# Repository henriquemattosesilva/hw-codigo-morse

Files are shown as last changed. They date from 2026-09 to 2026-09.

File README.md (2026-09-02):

# Telégrafo sem fio em código morse

Um manipulador de morse com um botão no Arduino Nano transmite por rádio
433 MHz para um receptor, que mostra a mensagem decodificada num LCD 16x2.
São **dois receptores possíveis**: um Arduino Uno, mais simples, e um ESP8266,
que além do LCD publica a mensagem na internet.

O botão é uma chave telegráfica de verdade: toque curto vira ponto, toque longo
vira traço, e as pausas separam as letras e as palavras. Você escreve qualquer
coisa, não uma mensagem programada de antemão.

```
   botão                                            LCD 16x2
     │                                                 ▲
     ▼                                                 │
   NANO  ──►  433 MHz  ))))))))))))))))))))  ──►  UNO ─┘
     │                                             │
  3 LEDs + buzzer                            LED + botão limpar
```

## Arquivos

**A página do projeto reúne tudo — componentes, montagem com diagramas, código das
duas placas e melhorias — numa tela só, boa de consultar no celular durante a montagem:**

### 👉 https://henriquemattosesilva.github.io/hw-codigo-morse/

Ela também traz um manipulador de morse que funciona no navegador, com os mesmos LEDs
e o mesmo display do projeto real. Dá para treinar antes de montar qualquer coisa.

| Arquivo | O que é |
|---|---|
| [index.html](index.html) | a página do projeto, publicada no GitHub Pages |
| [MONTAGEM.md](MONTAGEM.md) | esquema de ligação, ordem de teste e o que fazer quando não funciona |
| [transmissor-nano/](transmissor-nano/) | sketch do Nano (manipulador) |
| [receptor-uno/](receptor-uno/) | sketch do Uno (display) |
| [receptor-esp8266/](receptor-esp8266/) | sketch do ESP8266 (display + internet) |
| [MONTAGEM-ESP8266.md](MONTAGEM-ESP8266.md) | montagem do receptor com ESP8266 |
| [ao-vivo/](ao-vivo/) | a página que mostra a mensagem ao vivo |
| [ferramentas/](ferramentas/) | scripts que geram os diagramas e a página |
| [docs/superpowers/specs/](docs/superpowers/specs/) | o projeto escrito, com as decisões e os porquês |

O `index.html` é **gerado**, não editado à mão. Depois de mexer num sketch ou nos
diagramas, rode:

```
python ferramentas/gerar-diagramas.py   # só se mudou a fiação
python ferramentas/gerar-pagina.py      # sempre
```

## Os dois receptores

| | Arduino Uno | ESP8266 |
|---|---|---|
| Lógica | 5 V, liga o rádio direto | 3,3 V, **exige divisor** no DATA do rádio |
| Pinos | qualquer um serve | três são lidos no boot e mudam quem vai onde |
| Rádio | sozinho no processador | disputando com a pilha de WiFi |
| Mensagem | 15 letras no LCD | 160 guardadas, 15 no LCD, e **na internet** |

**Comece pelo Uno.** Ele prova que o rádio funciona sem trazer junto WiFi, tensão de
3,3 V e divisor resistivo. Trocar a placa da ponta depois é rápido.

Com o telégrafo com ESP8266 ligado, a mensagem aparece ao vivo em
**https://henriquemattosesilva.github.io/hw-codigo-morse/ao-vivo/** — a montagem está
no [MONTAGEM-ESP8266.md](MONTAGEM-ESP8266.md).

> A saída de dados do módulo de rádio entrega 5 V, e os pinos do ESP8266 não toleram
> isso. O divisor de 10 kΩ + 20 kΩ não é opcional.

**Comece pelo [MONTAGEM.md](MONTAGEM.md).** A única biblioteca a instalar é a
**RadioHead**, pelo Gerenciador de Bibliotecas da IDE.

## Os LEDs do transmissor

O difícil no morse é que os tempos são invisíveis: você não sabe se o aperto já
virou traço até a letra sair errada. Os três LEDs mostram exatamente os limiares,
e acendem **antes** de você soltar o botão.

| O que você vê | O que significa |
|---|---|
| um verde aceso | o toque em curso ainda vale um **ponto** |
| os **dois** verdes acesos | o toque passou de 2 unidades, virou **traço** |
| azul aceso | o silêncio passou de 3 unidades: a **letra fechou e foi enviada** |
| azul piscando duas vezes | o silêncio passou de 7 unidades: **espaço** enviado |

Na prática você bate no botão contando os LEDs acesos, e solta quando o
símbolo que quer estiver na tela. O buzzer apita junto, para o ouvido acompanhar.

## A velocidade

Todo o morse é medido em múltiplos de uma **unidade** de tempo. Aqui ela vale
250 ms — lento, e bom para aprender. É a constante `UNIDADE`, no topo do sketch
do transmissor: número maior deixa o morse mais lento.

| Evento | Duração |
|---|---|
| ponto | 1 unidade |
| traço | 3 unidades |
| pausa entre pontos e traços da mesma letra | 1 unidade |
| pausa entre letras | 3 unidades |
| pausa entre palavras | 7 unidades |

O código separa ponto de traço em **2 unidades**, que é o meio do caminho entre
1 e 3. Com 250 ms, isso quer dizer meio segundo: segurou mais que isso, virou
traço.

Não existe potenciômetro de velocidade no transmissor. Ele chegou a ter um, e
saiu: a faixa que cobria ia até 60 ms, rápido demais para ser útil, e o extremo
lento era o único ponto usado.

## O alfabeto

```
A ·−      H ····    O −−−     V ···−     2 ··−−−    7 −−···
B −···    I ··      P ·−−·    W ·−−      3 ···−−    8 −−−··
C −·−·    J ·−−−    Q −−·−    X −··−     4 ····−    9 −−−−·
D −··     K −·−     R ·−·     Y −·−−     5 ·····    0 −−−−−
E ·       L ·−··    S ···     Z −−··     6 −····
F ··−·    M −−      T −                  1 ·−−−−
G −−·     N −·      U ··−
```

Comece por `E` (·), `T` (−), `A` (·−) e `N` (−·). `SOS` é `··· −−− ···`.

Uma sequência que não existe no alfabeto vira `?` — não trava nada, e é a forma
mais rápida de perceber que o timing está fora.

## Como a mensagem viaja

O Nano decodifica a letra antes de transmitir, e o que vai pelo ar é um pacote
de 3 bytes: uma marca `'M'`, um número de sequência e o caractere.

Mandar os pontos e traços crus pelo rádio seria mais fiel a um telégrafo, mas o
433 MHz AM é ruidoso e perde pulsos curtos com facilidade — as letras chegariam
erradas o tempo todo. Decodificando antes, uma interferência ou some com a letra
inteira ou não a afeta; ela nunca vira outra letra.

Como não existe canal de retorno, **cada letra é transmitida três vezes**. O
receptor usa o número de sequência para descartar as repetições, então a letra
só aparece uma vez no display. Uma perda isolada não come nada.

## Ajustes rápidos

| Quero | Onde mexer |
|---|---|
| Mais alcance, aceitando lentidão | `RH_ASK radio(1000);` nos **dois** sketches |
| Ambiente muito ruidoso | `REPETICOES` de 3 para 5, no transmissor |
| Morse mais lento ou mais rápido | `UNIDADE`, no transmissor. Maior é mais lento |
| Botão registrando toques em dobro | aumente `DEBOUNCE_MS` para 40 |
| Buzzer dá um clique em vez de apitar | ele é passivo: use `tone()` no lugar de `digitalWrite` |

Se mudar a velocidade do rádio, mude **nos dois lados**. Com bitrates
diferentes, um lado não escuta o outro e não há nenhuma mensagem de erro.

---

# Melhorias

## Alcance

**Antena de 17,3 cm nos dois módulos.** Esta é, de longe, a que mais muda o
resultado: sem antena o alcance é de centímetros, com antena passa de 30 metros
em campo aberto. Já está no [MONTAGEM.md](MONTAGEM.md), mas vale repetir porque
é comum deixar para depois e concluir que o rádio é ruim.

**Alimentar o transmissor com mais tensão.** O módulo 433 MHz aceita de 3 V a
12 V, e a potência sobe junto. Em 5 V ele está na base da faixa. Ligue uma
bateria de 9 V no `VIN` do Nano e alimente o VCC do módulo pelo próprio `VIN`,
não pelo 5 V. O pino DATA continua em 5 V, o que é normal — o módulo só usa a
tensão maior para transmitir.

**Capacitor de desacoplamento no receptor.** Um de 100 nF em paralelo com um de
10 µF entre o VCC e o GND do módulo receptor, o mais perto possível dos pinos.
O receptor AM é sensível a ruído na alimentação, e o LCD com a luz de fundo
puxando corrente é justamente uma fonte de ruído. Você não tem capacitores na
lista de componentes — valem a compra, custam centavos e servem em todo projeto
daqui para frente.

**Afaste as antenas dos cabos USB e das fontes chaveadas.** Carregador de
celular perto da bancada derruba o alcance de forma dramática.

## Uso

**Manipulador iâmbico (a evolução clássica).** Com duas chaves tácteis em vez de
uma, o Arduino gera os pontos e traços com a duração certa sozinho: segure a
esquerda e saem pontos perfeitos, segure a direita e saem traços perfeitos. É
como todo radioamador opera hoje, e resolve de vez o problema de acertar a
duração na mão. Você tem 19 chaves tácteis sobrando.

**Chave táctil emborrachada como manipulador.** Você tem quatro delas, e o toque
macio é bem mais confortável para bater morse do que o clique seco da chave
comum.

**Sensor touch TTP223B no lugar do botão.** Você tem um. Manipular por toque,
sem parte móvel, fica bem mais parecido com uma chave telegráfica moderna.

**Chave SS de 2 posições para escolher o modo.** Você tem três. Uma posição
manipula livre, a outra dispara uma mensagem pronta (`SOS`, seu indicativo)
inteira em morse a cada aperto.

**Brilho da luz de fundo por software.** Em vez do resistor fixo no pino 15 do
LCD, use um transistor C945 (você tem dez) comandado por um pino PWM do Uno.
Aí o brilho vira uma variável no código, e não uma peça soldada.

## Evoluções, todas com peças que você já tem

**Registrador telegráfico.** Junte o módulo de cartão SD com o RTC DS1307 no
receptor e grave cada mensagem recebida com data e hora. Vira um projeto
completo por si só, e é o passo natural depois que este funcionar.

**A letra em tamanho grande.** A matriz de LED 8x8 com MAX7219 no receptor,
mostrando a letra que acabou de chegar enquanto o LCD segue com o texto. Fica
ótimo de ver de longe.

**Mais texto na tela.** O display Nokia 5110 cabe várias linhas e permite manter
um histórico em vez de só as últimas 15 letras.

**Mensagens na internet.** O ESP8266 no lugar do Uno como receptor, publicando o
que chega. Aí o telégrafo alcança qualquer lugar, não 30 metros.

**Áudio no lado que recebe.** Um segundo buzzer no receptor, reproduzindo o
morse da letra que chegou. Você só tem um buzzer, e ele faz mais falta no
transmissor como sidetone — mas com um buzzer **passivo** e a função `tone()`
dá para escolher a frequência do apito, o que soa muito mais parecido com um
rádio de verdade do que o bipe fixo do buzzer ativo.

## Cuidados

**Comunicação nos dois sentidos exige mais peças.** Você tem um transmissor e um
receptor; para conversar nos dois sentidos precisaria de mais um par. Não dá
para usar o mesmo módulo nas duas funções.

**A faixa de 433 MHz é compartilhada.** Portões eletrônicos, campainhas sem fio
e sensores de alarme usam a mesma frequência e vão aparecer como ruído. O CRC da
biblioteca barra quase tudo, e a marca `'M'` do pacote barra o resto — mas se
o vizinho tiver um portão que dispara muito, espere alguma perda de pacote.

**Não há criptografia.** Qualquer receptor 433 MHz na vizinhança consegue ler o
que você transmite. Para um projeto de bancada tanto faz; só não mande nada que
importe.

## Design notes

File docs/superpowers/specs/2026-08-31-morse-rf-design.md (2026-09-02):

# Telégrafo sem fio em código morse — 433 MHz

Data: 2026-08-31

## Objetivo

Um manipulador de morse com um botão no Arduino Nano transmite por rádio
frequência 433 MHz para um Arduino Uno, que exibe a mensagem decodificada em um
display LCD 16x2. A montagem inicial é em protoboard.

## Componentes usados

Todos já estão no inventário em `../Componentes`.

| Peça | Qtd | Lado |
|---|---|---|
| Arduino Nano V3.0 | 1 | transmissor |
| Arduino Uno R3 | 1 | receptor |
| Módulo Transmissor RF 433MHz AM | 1 | transmissor |
| Módulo Receptor RF 433MHz AM | 1 | receptor |
| Display LCD 16x2 | 1 | receptor |
| Chave táctil | 2 | 1 manipulador, 1 limpar tela |
| Potenciômetro linear 10K | 2 | 1 velocidade, 1 contraste |
| LED verde 5mm difuso | 2 | transmissor, ponto e traço |
| LED azul 5mm difuso | 1 | transmissor, letra e espaço |
| LED vermelho 5mm difuso | 1 | receptor |
| Resistor 220Ω | 5 | 4 LEDs + backlight do LCD |
| Protoboard 830 pontos | 2 | um por lado |

## Arquitetura

Duas peças independentes acopladas apenas por um pacote de três bytes. Nenhum
dos lados conhece o estado interno do outro.

```
[botão] -> Nano: máquina de estados de timing -> letra -> RF 433MHz
                                                            |
        LCD 16x2 <- morse reconstruído <- letra <- Uno: RH_ASK  |
```

### Tabela morse compartilhada

Os dois sketches usam a mesma árvore binária de 63 bytes em PROGMEM:

```
"*ETIANMSURWDKGOHVF*L*PJBXCYZQ**54*3***2*******16*******7***8*90"
```

A partir do índice 0 (raiz vazia), ponto desce para `2i+1` e traço para `2i+2`.
O transmissor desce a árvore para achar a letra. O receptor faz o caminho
inverso: localiza a letra na tabela e sobe pelos pais (`(i-1)/2`), em que
`(i-1)%2 == 0` significa ponto e `1` significa traço. Uma tabela só, nos dois
lados, sem risco de divergirem.

`*` marca posições sem letra correspondente. Um índice acima de 62 ou apontando
para `*` produz `?`.

### Transmissor (Nano)

Máquina de estados sobre a duração dos toques, com a unidade de tempo lida do
potenciômetro em A0 (250 ms a 60 ms, do mais lento ao mais rápido). A unidade é
relida apenas quando o manipulador está ocioso, para não alterar os limiares no
meio de uma letra.

Limiares, em unidades:

| Evento | Limiar | Efeito |
|---|---|---|
| Toque solto antes de 2u | < 2u | símbolo é ponto |
| Toque solto depois de 2u | >= 2u | símbolo é traço |
| Silêncio com símbolos no buffer | >= 3u | fecha a letra, decodifica, transmite |
| Silêncio depois de fechar a letra | >= 7u | transmite espaço de palavra |

Debounce de 25 ms na borda de descida; toques abaixo disso são descartados.
O buffer de símbolos tem 6 posições; um sétimo símbolo força o fecho da letra
como `?` em vez de estourar o buffer.

LEDs como limiares ao vivo, para dar retorno antes de o operador soltar:

- um verde acende ao tocar (o símbolo em curso é um ponto)
- o segundo verde acende junto quando a duração cruza 2u (virou traço).
  Dois LEDs iguais em vez de duas cores: conta-se quantos estão acesos
- azul acende quando o silêncio cruza 3u (letra fechada e transmitida) e dá um
  pisca duplo antes de apagar quando cruza 7u (espaço de palavra transmitido)

O buzzer ativo apita enquanto o botão está pressionado, como sidetone. Ele tem
apenas dois pinos, S e GND, então é o próprio D4 que o alimenta ao ir para
nível alto — 20 a 30 mA num pino que recomenda 20 mA.

### Protocolo de rádio

Biblioteca RadioHead `RH_ASK` a 2000 bps, que já fornece preâmbulo, codificação
4b6b e CRC-16. Pacote de 3 bytes:

| Byte | Conteúdo |
|---|---|
| 0 | `'M'`, marca de aplicação |
| 1 | número de sequência, 0-255, incrementado a cada caractere novo |
| 2 | o caractere ASCII |

Cada caractere é transmitido três vezes seguidas. O 433 AM perde pacotes com
facilidade e não há canal de retorno, então a redundância é a única defesa. O
receptor descarta o pacote cujo número de sequência for igual ao último aceito,
de modo que as repetições não escrevem letras duplicadas. Um caractere
legitimamente repetido (`SS`) recebe números de sequência diferentes e passa.

### Receptor (Uno)

Layout do LCD:

```
linha 1:  ·-··  L         *
linha 2:  CHAMANDO_
```

Linha 1: o morse reconstruído da última letra (colunas 0-5), a letra (coluna 7)
e um indicador de recepção na coluna 15 que aparece por 150 ms a cada pacote
válido. Linha 2: as últimas 16 letras recebidas, rolando para a esquerda quando
enche, com um cursor `_` na posição seguinte.

Ponto e traço são caracteres customizados do HD44780, desenhados centralizados
na altura da linha. Um `.` e um `-` do próprio charset ficariam na base e no
meio, desalinhados entre si.

O LED vermelho acende por 150 ms a cada pacote válido. A segunda chave táctil
limpa o texto acumulado.

O LCD só é reescrito quando algo muda. `RH_ASK` roda numa interrupção de Timer1
a 16 kHz e as escritas no LCD são lentas; redesenhar a tela a cada volta do loop
aumenta a chance de perder pacotes.

## Pinagem

### Nano — transmissor

| Pino | Ligação |
|---|---|
| D2 | chave táctil (INPUT_PULLUP, outro terminal ao GND) |
| D3 | LED verde (ponto) + 220Ω |
| D4 | buzzer ativo de 2 pinos: S no pino, GND no terra. Sem VCC — o pino é que alimenta |
| D5 | LED verde 2 (traço) + 220Ω |
| D6 | LED azul (espaço/letra) + 220Ω |
| D12 | DATA do módulo transmissor RF |
| A0 | cursor do potenciômetro 10K (velocidade) |

### Uno — receptor

| Pino | Ligação |
|---|---|
| D2 | LCD RS |
| D3 | LCD E |
| D4-D7 | LCD D4-D7 |
| D8 | LED vermelho (pacote recebido) + 220Ω |
| D9 | chave táctil (limpar tela, INPUT_PULLUP) |
| D11 | DATA do módulo receptor RF |
| A0 | livre |

D12 no Nano e D11 no Uno são os padrões da `RH_ASK` no AVR. Mantidos como estão
para não precisar reconfigurar a biblioteca.

## Tratamento de erro

| Falha | Comportamento |
|---|---|
| Sequência de pontos e traços sem letra | transmite `?` |
| Mais de 6 símbolos numa letra | fecha como `?` |
| Toque menor que o debounce | descartado, nada é registrado |
| Pacote corrompido no ar | CRC da `RH_ASK` rejeita, nada aparece |
| Pacote perdido no ar | as duas repetições cobrem |
| Repetição recebida | descartada pelo número de sequência |
| Pacote sem a marca `'M'` ou de tamanho errado | ignorado |

Ruído de 433 MHz do ambiente (portões, campainhas) é filtrado pela combinação de
CRC, marca `'M'` e tamanho fixo de 3 bytes.

## Verificação

Não há como testar automaticamente o rádio ou o LCD sem o hardware montado. A
verificação possível antes da bancada é a compilação dos dois sketches com
`arduino-cli` para `arduino:avr:nano` e `arduino:avr:uno`, checando também que o
uso de RAM deixa folga no Nano.

Na bancada, a ordem de teste é: primeiro o transmissor sozinho pelo monitor
serial (confere a decodificação dos toques sem envolver o rádio), depois o
receptor com os dois lado a lado, e só então a distância.

## Fora de escopo

Confirmação de recebimento, retransmissão sob demanda, criptografia,
comunicação bidirecional e pontuação além de letras e números. O manipulador
cobre A-Z, 0-9 e espaço.

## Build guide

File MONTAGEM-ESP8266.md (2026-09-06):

# Montagem do receptor com ESP8266

Este é o receptor que, além de mostrar no LCD, publica a mensagem na internet.
Substitui o Arduino Uno; o transmissor com o Nano não muda em nada.

A versão com Uno continua no projeto e é mais simples. Se você nunca montou o
rádio antes, **monte primeiro a versão com Uno**: ela prova que o rádio funciona
sem trazer junto WiFi, tensão de 3,3 V e divisor resistivo. Aí é só trocar a
placa da ponta.

---

## As três diferenças que importam

### 1. O ESP8266 é 3,3 V e o módulo de rádio é 5 V

A saída `DATA` do receptor de 433 MHz entrega cerca de 5 V. Os pinos do ESP8266
não toleram isso: ligar direto vai degradar o pino com o tempo, e pode matá-lo
de uma vez. Entre os dois vai um divisor resistivo.

O módulo tem **quatro pinos, mas três ligações**: os dois `DATA` do meio são o
mesmo ponto, ligados por dentro da plaquinha. Use qualquer um dos dois e deixe o
outro livre.

```
              módulo receptor 433 MHz
        ┌────────────────────────────────────┐
        │   GND     DATA     DATA      VCC   │
        └────┬────────┬─────────┬────────┬───┘
             │        │         │        │
             │        │    (deixe livre) │
             │        │                  │
             G     [10 kΩ]              VU
                      │
                      ├──────────►  D2 do ESP8266   (3,33 V)
                      │
                   [10 kΩ]
                      │
                   [10 kΩ]
                      │
                      G      o mesmo terra do ESP
```

**O desenho acima é a vista da serigrafia, que fica no verso da plaquinha:** `GND` no
primeiro pino e `VCC` no quarto. **Virando o módulo para cima a ordem espelha** — de cima
o `VCC` é que vem primeiro, e é assim que o sketch do Fritzing o desenha. As duas leituras
estão certas; o que engana é comparar uma com a outra sem lembrar de que lado se está
olhando.

A ordem também varia entre fabricantes, então confira a sua plaquinha de qualquer jeito.
Ligar pela figura sem olhar foi o que segurou este projeto por duas sessões.

`VCC` vai no **`VU`**, que é o 5 V da USB — **nunca no `3V3`**. Este receptor é
superregenerativo e não estabelece ganho em 3,3 V: fica mudo, sem nenhum aviso, e o
sintoma é idêntico ao de um módulo queimado. `GND` vai no `G`, e é esse mesmo `G` que
fecha o pé do divisor: se os dois terras não forem o mesmo, a conta do divisor não
vale.

Os dois resistores de baixo, em série, somam 20 kΩ:
`5 V × 20 kΩ ÷ (10 kΩ + 20 kΩ) = 3,33 V`. Você tem 19 resistores de 10 kΩ, e
esta montagem usa três.

**Não pule esta parte nem para "só testar rápido".** É o tipo de dano que não
aparece na hora e depois deixa você caçando um defeito que parece de software.

### 2. Cada pino de boot leva a peça que empurra para o lado certo

O ESP8266 lê o nível de três pinos no instante em que liga, para decidir como
inicializar: **GPIO0 e GPIO2 têm que estar em nível alto, e GPIO15 em nível
baixo**. Com o nível errado ele não arranca, ou não aceita gravação.

Não é uma preocupação teórica. A primeira versão desta montagem punha o LCD nos
três, no raciocínio de que as entradas dele ficam em alta impedância e não
perturbariam nada. **Na bancada isso se mostrou falso**: o LCD é alimentado em
5 V pelo `VU`, e a fuga pelos diodos de proteção da entrada RS puxava o GPIO15
para cima, vencendo o resistor de 12 kΩ da placa. O ESP entrava em modo SDIO e
a gravação morria em `Timed out waiting for packet header`. Tirar aquele fio
único fazia gravar de novo.

Por isso os três pinos delicados agora ficam com peças compatíveis:

| Pino | Precisa | O que ficou nele | Por quê |
|---|---|---|---|
| GPIO0 (D3) | alto | chave de limpar | botão aberto + pull-up interno = alto. É como o próprio botão FLASH da placa é ligado |
| GPIO2 (D4) | alto | uma linha de dados do LCD | a fuga dos 5 V puxa para cima — justamente o nível que este pino quer |
| GPIO15 (D8) | baixo | LED vermelho | o LED não puxa para lado nenhum abaixo da tensão direta dele; o mérito é **não brigar** com o resistor da placa |

Repare que o LED **não é** um resistor de pull-down: abaixo de uns 2 V ele é
praticamente circuito aberto. Quem segura o GPIO15 é o resistor que já está na
placa. O que mudou é que agora nada disputa com ele.

**O rádio continua fora dos três**, e por um motivo diferente: enquanto não há
transmissão, a saída do receptor AM é **ruído aleatório**. Num pino de boot,
seria cara ou coroa a cada vez que você ligasse.

**Efeito colateral do botão no GPIO0:** segurar a chave de limpar enquanto a
placa reseta faz o ESP entrar em modo de gravação. Não segure no reset.

### 3. WiFi e rádio disputam o mesmo processador

A `RH_ASK` no ESP8266 usa o timer0 para amostrar o pino oito vezes por bit, e a
pilha de WiFi desliga a interrupção de vez em quando para cuidar do rádio dela.
Isso pode comer um pacote aqui e ali — coisa que a versão com Uno não tem.

As três repetições de cada letra, que já existiam por causa do ruído de 433 MHz,
cobrem a maior parte disso. Se ainda assim faltar letra, subir `REPETICOES` no
transmissor para 5 é o primeiro ajuste.

---

## A placa

A sua é uma **NodeMCU v3 (LoLin)**, de PCB preto e conversor CH340G.

**Ela é larga demais para protoboard.** Os 25,5 mm cobrem o canal central e
quase todas as fileiras dos dois lados, sobrando no máximo uma coluna de furos —
não dá para trabalhar. Deixe a placa fora da protoboard e ligue por **jumpers
macho-fêmea** direto nos headers dela. Você tem 80.

**Use o pino `VU`, não o `3V3`.** O `VU` é o 5 V da USB, e é dele que saem a
alimentação do LCD e do módulo de rádio. Fica na fileira de baixo, entre `G` e
`S3`. O `VIN` é entrada de energia, não saída.

---

## Ligações

| Função | Pino da placa | GPIO | Observação |
|---|---|---|---|
| LCD RS | **D1** | 5 | |
| LCD E | **D0** | 16 | é também um LED da placa, que vai piscar |
| LCD D4 | **D4** | 2 | pino de boot; é também o LED do módulo, que vai piscar |
| LCD D5 | **D5** | 14 | |
| LCD D6 | **D6** | 12 | |
| LCD D7 | **D7** | 13 | |
| DATA do rádio | **D2** | 4 | **atrás do divisor**, nunca direto. Qualquer um dos dois DATA |
| VCC do rádio | **VU** | — | o 5 V da USB, não o `3V3` |
| Chave de limpar | **D3** | 0 | outro terminal no `G`. Pino de boot — não segure no reset |
| LED vermelho | **D8** | 15 | com resistor de 220 Ω. Pino de boot |
| 5 V do LCD (pinos 2 e 15) | **VU** | — | o mesmo `VU` do rádio |
| Terra | **G** | — | |

O LCD liga igual à versão com Uno, menos a alimentação: os pinos 2 e 15 vão ao
`VU`, não a um pino de 5 V do Arduino. O pino 5 (RW) continua obrigatoriamente
no terra, e o contraste continua no potenciômetro pelo pino 3.

### Um detalhe que pode dar trabalho

O LCD é alimentado com 5 V mas recebe sinais de 3,3 V. Pela folha de dados, o
HD44780 quer 3,5 V para reconhecer nível alto — 3,3 V está tecnicamente abaixo.
Na prática a maioria dos módulos aceita sem reclamar, e é por isso que vamos
assim.

Se a tela mostrar lixo, blocos, ou nada com o contraste bem ajustado, o problema
é esse. A correção é baixar a tensão do LCD: um diodo comum em série com o pino
2 derruba uns 0,7 V, e a 4,3 V o limite cai para cerca de 3,0 V, abaixo dos
3,3 V que o ESP entrega. Você não tem diodos avulsos, mas a junção base-emissor
de um transistor **C945** funciona como um: base e coletor juntos formam o
anodo, o emissor é o catodo. Você tem dez.

---

## Antes de gravar

Copie `receptor-esp8266/segredos-exemplo.h` para `receptor-esp8266/segredos.h` e
preencha:

```c
#define WIFI_SSID   "sua-rede"
#define WIFI_SENHA  "sua-senha"
#define MQTT_TOPICO_BASE "hw-codigo-morse/algo-so-seu"
```

O `segredos.h` está no `.gitignore`: **a senha do seu WiFi não vai para o
GitHub.** Sem esse arquivo o sketch não compila, e isso é de propósito.

O `MQTT_TOPICO_BASE` precisa ser **exatamente igual** ao `TOPICO_BASE` que está
em `ao-vivo/index.html`. Se os dois não baterem, a página fica escutando um
telégrafo que não é o seu — sem nenhum erro na tela, simplesmente nunca chega
nada.

Troque o sufixo por algo só seu. O broker é público e sem senha: quem souber o
nome do tópico lê o que você transmite, e escreve nele.

**Placa a selecionar na IDE:** *NodeMCU 1.0 (ESP-12E Module)*. Bibliotecas:
RadioHead, PubSubClient e LiquidCrystal.

---

## Ordem de teste

**1. Só a placa e o LCD.** Grave o sketch sem ligar o rádio ainda. Gire o
potenciômetro de contraste de ponta a ponta até aparecer `MORSE + WiFi` e
`ligando WiFi...`. Se a tela não acender nada em ponto nenhum do curso, pare
aqui: é contraste, alimentação ou o RW solto.

**2. O WiFi.** Depois de conectar, o canto direito da linha 1 mostra o estado:
vazio sem WiFi, `w` com WiFi mas sem o broker, e um desenho de antena quando os
dois estão de pé. O monitor serial em **115200** conta o resto.

**3. A página ao vivo.** Abra
[a página](https://henriquemattosesilva.github.io/hw-codigo-morse/ao-vivo/) com
o telégrafo ligado: a bolinha do canto tem que ficar verde e dizer "telégrafo
ligado", mesmo sem nenhuma letra ter chegado ainda. Isso já prova o caminho
inteiro até a internet, antes de envolver o rádio.

**4. O rádio.** Aí sim, ligue o receptor com o divisor e bata um `E` no
transmissor.

---

## Quando não funciona

| Sintoma | Causa provável |
|---|---|
| A placa não inicia, ou entra em modo de gravação sozinha | algo está segurando GPIO0, GPIO2 ou GPIO15 no nível errado no boot. O rádio não pode estar em nenhum desses |
| `Timed out waiting for packet header` com o LCD ligado | **aconteceu de verdade:** era o RS do LCD no D8. Confira se o RS está no **D1**, e não no D8 — este projeto trocou esses pinos justamente por isso |
| A placa entra em modo de gravação ao resetar | você segurou a chave de limpar. Ela está no GPIO0, o mesmo pino do botão FLASH |
| `Timed out waiting for packet header` na gravação | **primeiro** confira se a porta é mesmo a do ESP: o Nano e a NodeMCU aparecem os dois como `USB-SERIAL CH340`, e a lista de portas não distingue. Desconecte o Nano e veja qual porta some |
| `could not open port` na gravação | a porta sumiu naquele instante — quase sempre o cabo desencostou. O Windows leva alguns segundos para reenumerar |
| Ao resetar, o serial mostra caracteres quebrados e só depois o texto | normal: o bootloader de ROM fala a 74880 bauds, taxa fixa de fábrica. O que vem depois é o seu programa, a 115200 |
| Quer testar WiFi e página sem montar nada | pode: `radio.init()` não detecta hardware, então a placa pelada conecta igual. É a forma mais limpa de separar rede de rádio |
| Tela com lixo ou blocos, contraste bem ajustado | os 3,3 V do ESP estão no limite para o LCD: veja o truque do diodo acima |
| Quadrados pretos e o contraste não muda nada | **aconteceu de verdade em 06/09/2026:** o pino 5 (RW) estava num ponto do trilho negativo que não era o terra da placa. O LCD acende, mas não executa comando nenhum. Ligue o RW direto no `G` do ESP e veja a linha do trilho partido, abaixo |
| Uma peça não funciona e a fiação confere | **aconteceu de verdade em 06/09/2026:** o trilho de alimentação da protoboard é partido no meio em muitas placas, e as duas metades não se falam. Olhe a linha pintada de ponta a ponta procurando a interrupção, e una as metades com um jumper |
| LCD apagado e o `3V3` foi usado | o LCD precisa do `VU`; em 3,3 V ele não funciona direito |
| A bolinha da página nunca fica verde | o tópico da página e o do `segredos.h` estão diferentes |
| Página verde mas nenhuma letra | o problema é o rádio, não a internet. **Antes de qualquer teoria, confira a alimentação do módulo:** o `VCC` dele tem de estar no `VU`, e no pino certo da plaquinha |
| Nada chega, e o transmissor está comprovadamente certo | **aconteceu de verdade, duas vezes seguidas:** o módulo estava sem 5 V. Uma vez porque o fio do `VU` estava num dos `DATA`, outra porque a linha `+` da protoboard vinha do `3V` |
| A ordem dos pinos do módulo não bate com o diagrama | o desenho segue a plaquinha desta bancada, `GND` primeiro e `VCC` no quarto. Há versões com a ordem invertida: **vá pela serigrafia, não pela figura** |
| Faltam letras que a versão com Uno pegava | WiFi disputando com o rádio: suba `REPETICOES` para 5 no transmissor |
| `WiFi` conecta e cai o tempo todo | alimentação; o ESP puxa picos de corrente ao transmitir |
| Os LEDs da placa piscam sozinhos ao escrever no LCD | é normal: GPIO2 e GPIO16 são LEDs da placa e ao mesmo tempo linhas do LCD (D4 e E) |

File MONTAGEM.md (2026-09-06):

# Montagem em protoboard

Duas protoboards independentes, uma para cada lado. Nada liga uma na outra —
a única ligação entre elas é o rádio.

Monte primeiro o transmissor inteiro e teste pelo monitor serial. Só depois
monte o receptor. Assim, se algo não funcionar, você sabe de que lado está.

---

## Antes de começar

**Sempre desligue o USB antes de mexer na fiação.** Ligar um fio no lugar errado
com a placa energizada é a forma mais comum de queimar um pino.

**Pinos que a biblioteca do rádio reserva sozinha.** A `RH_ASK` configura três
pinos por conta própria, mesmo que você não os use. Deixe-os vazios:

| Placa | Reservados | Uso |
|---|---|---|
| Nano | D10, D11, **D12** | D12 é o DATA do transmissor; D10 e D11 ficam vazios |
| Uno | D10, **D11**, D12 | D11 é o DATA do receptor; D10 e D12 ficam vazios |

**D0 e D1 são a USB.** Não use nos dois lados, ou o monitor serial para de
funcionar e o upload falha.

**Identificando o LED.** A perna longa é o anodo (+, vai para o resistor). A
perna curta fica do lado chanfrado do corpo e é o catodo (−, vai para o GND).

**Identificando a chave táctil.** Os quatro pinos são, na verdade, dois pares
já ligados internamente. Se você usar o par errado, a chave fica sempre
fechada. O jeito seguro é montá-la atravessando o canal central da protoboard e
usar **dois pinos na diagonal**.

---

## Lado A — Transmissor (Arduino Nano)

Encaixe o Nano atravessando o canal central da protoboard. Ligue o pino **5V**
do Nano na trilha vermelha (+) e o **GND** na trilha azul (−) das laterais.

### Ligações

| Componente | Ligação |
|---|---|
| Chave táctil (manipulador) | um pino → **D2**, pino na diagonal → GND (−) |
| LED **verde 1** (ponto) | **D3** → resistor 220 Ω → anodo; catodo → GND (−) |
| Buzzer ativo (2 pinos) | S → **D4**; GND → GND (−). Não tem pino de VCC |
| LED **verde 2** (traço) | **D5** → resistor 220 Ω → anodo; catodo → GND (−) |
| LED **azul** (espaço) | **D6** → resistor 220 Ω → anodo; catodo → GND (−) |
| Módulo transmissor 433 MHz | DATA → **D12**; VCC → 5V (+); GND → GND (−) |

**A velocidade é fixa, definida no código.** Não há potenciômetro neste lado. A
constante `UNIDADE`, no topo do `transmissor-nano.ino`, vale 250 ms — lento e
bom para aprender. Para mudar o ritmo, troque esse número e regrave.

**O buzzer não tem pino de alimentação.** Com apenas S e GND, quem alimenta o
buzzer é o próprio pino D4: ao ir para nível alto, ele fornece os 5 V e a
corrente. É assim que os buzzers de dois pinos funcionam, mas repare que são uns
20 a 30 mA saindo de um pino só. O ATmega328 recomenda 20 mA por pino e admite
40 mA no limite absoluto, então isso fica no teto do recomendado.

Funciona direto, e é como esses buzzers são usados em qualquer kit. Se quiser
poupar o pino, um transistor **C945** com um resistor de 10 kΩ na base faz o
buzzer puxar corrente do 5 V em vez do D4 — você tem dez transistores e dezenove
resistores de 10 kΩ.

O módulo transmissor tem só três pinos e costuma vir com a serigrafia
`DATA / VCC / GND` (às vezes escrita `ATAD`). O furo maior sozinho, num canto
da plaquinha, é o da antena.

### Vista de cima

```
                        trilha +  (5V)
   ┌──────────────────────────────────────────────┐
   │            [BUZZER]             [TX 433MHz]  │
   │             │  │                 │   │   │   │
   │             D4 −                D12  +   −   │      antena: fio reto
   │                                               │      de 17,3 cm no furo ANT
   │        ┌───────────────────┐                  │
   │        │   ARDUINO NANO    │                  │
   │        │  D2 D3 D4 D5 D6   │                  │
   │        └───┬──┬──┬──┬──┬───┘                  │
   │            │  │  │  │  │                      │
   │       [CHAVE] │  │  │  │                      │
   │            │ 220 │ 220 220                    │
   │            │  │  │  │  │                      │
   │            │ LED│ LED LED                     │
   │            │verde verde azul                  │
   └────────────┴──┴──┴──┴──┴──────────────────────┘
                        trilha −  (GND)
```

---

## Lado B — Receptor (Arduino Uno)

O Uno fica fora da protoboard, ligado a ela por jumpers macho-fêmea. Ligue o
**5V** e o **GND** do Uno nas trilhas da protoboard antes de tudo.

### Display LCD 16x2

O LCD tem 16 pinos, numerados da esquerda para a direita olhando a frente do
display com os pinos na parte de cima.

| Pino do LCD | Nome | Vai para |
|---|---|---|
| 1 | VSS | GND (−) |
| 2 | VDD | 5V (+) |
| 3 | V0 | **cursor do potenciômetro 10K** (contraste) |
| 4 | RS | **D2** |
| 5 | RW | GND (−) |
| 6 | E | **D3** |
| 7 a 10 | D0–D3 | não ligar |
| 11 | D4 | **D4** |
| 12 | D5 | **D5** |
| 13 | D6 | **D6** |
| 14 | D7 | **D7** |
| 15 | A | resistor 220 Ω → 5V (+) |
| 16 | K | GND (−) |

O pino 5 (RW) **precisa** ir ao GND. Ele escolhe entre escrever e ler no
display; solto, o LCD fica com a tela em branco ou cheia de blocos pretos.

O resistor no pino 15 não é opcional. Vários módulos não têm resistor interno
na luz de fundo, e ligá-lo direto no 5V queima o LED do backlight.

Os pinos 3 (contraste) e 15 (luz de fundo) fazem coisas diferentes e são
confundidos o tempo todo. Se a tela acende mas não aparece nada, o problema é o
contraste, no pino 3.

### Demais ligações

| Componente | Ligação |
|---|---|
| Potenciômetro 10K (contraste) | esquerda → 5V (+); **cursor → pino 3 do LCD**; direita → GND (−) |
| Módulo receptor 433 MHz | DATA → **D11**; VCC → 5V (+); GND → GND (−) |
| LED **vermelho** (recebendo) | **D8** → resistor 220 Ω → anodo; catodo → GND (−) |
| Chave táctil (limpar tela) | um pino → **D9**, pino na diagonal → GND (−) |

O módulo receptor tem quatro pinos, e os **dois do meio são o mesmo DATA**,
ligados internamente. Use qualquer um dos dois. **A ordem varia entre
fabricantes:** no módulo desta bancada é `GND / DATA / DATA / VCC`, e existem
versões com o `VCC` no primeiro pino. Confira a serigrafia da sua plaquinha —
alimentar o módulo pelo pino errado o deixa mudo, e o sintoma é idêntico ao de
um rádio quebrado.

---

## Antenas

Sem antena o alcance é de uns poucos centímetros — dá para testar na bancada e
mais nada. Com antena, passa de 30 metros em campo aberto.

Corte **17,3 cm** de fio rígido em cada módulo e enfie no furo marcado `ANT`.
Essa medida é um quarto do comprimento de onda de 433 MHz e não é arbitrária:
encurtar ou alongar derruba o alcance. Deixe o fio o mais reto possível, para
cima, e afastado da placa e dos jumpers.

---

## Ordem de montagem e teste

Testar por partes é o que evita passar horas procurando um problema que está em
outro lugar.

**1. Bibliotecas.** Na IDE do Arduino, *Ferramentas → Gerenciar Bibliotecas*,
procure **RadioHead** (de Mike McCauley) e instale. A `LiquidCrystal` já vem
com a IDE.

**2. Transmissor sozinho.** Monte o lado A, envie o `transmissor-nano.ino` e
abra o monitor serial em **9600 baud**. Ao ligar, os três LEDs devem acender em
sequência e o buzzer dar um bipe — isso confirma a fiação sem multímetro.

Bata no botão. Cada letra fechada aparece no monitor assim:

```
.- = A
... = S
[espaco]
```

Aqui o rádio ainda não importa. Se as letras saem certas no serial, o
manipulador está bom.

**Placa a selecionar:** *Arduino Nano*, processador **ATmega328P**. Se o upload
der erro de sincronismo, troque para **ATmega328P (Old Bootloader)** — quase
todo Nano clone precisa disso.

**3. Receptor sozinho.** Monte o lado B e envie o `receptor-uno.ino`. Antes de
mais nada, gire o potenciômetro de contraste devagar de ponta a ponta: em algum
ponto do curso o texto `MORSE 433MHz` aparece. Se você não girar o
potenciômetro, é normal a tela parecer morta ou mostrar só uma fileira de
quadrados.

**4. Os dois juntos.** Deixe as duas protoboards a meio metro de distância.
Bata uma letra no botão: o LED vermelho pisca e a letra aparece no LCD.

**5. Distância.** Só depois que funcionar lado a lado, vá afastando.

---

## Quando não funciona

| Sintoma | Causa provável |
|---|---|
| LCD aceso, tela em branco | contraste: gire o potenciômetro ligado ao pino 3 |
| LCD com uma fileira de quadrados pretos | contraste no extremo errado — **ou** o display não está recebendo comando nenhum; veja duas linhas abaixo |
| LCD totalmente apagado | luz de fundo: confira o resistor no pino 15 e o pino 16 no GND |
| Tela em branco e contraste não resolve | pino 5 (RW) solto — precisa ir ao GND |
| Quadrados pretos e o contraste não muda nada | o LCD tem energia mas não executa comando nenhum. Na ordem: pino 5 (RW) no terra, pino 6 (E) ligado, e o terra do LCD sendo **o mesmo** da placa |
| Uma peça não funciona e a fiação confere | **aconteceu de verdade em 06/09/2026:** o trilho de alimentação da protoboard é partido no meio em muitas placas, e as duas metades não se falam. Olhe a linha pintada de ponta a ponta procurando a interrupção, e una as metades com um jumper |
| Letras erradas ou embaralhadas no LCD | inverta os fios de D4–D7 do LCD, é fácil trocar a ordem |
| Nada chega, mas o serial do Nano mostra as letras certas | antena faltando, ou DATA do receptor fora do D11 |
| Chegam letras aleatórias sem você bater nada | ruído de 433 MHz de portão ou campainha; é normal que apareça pouca coisa, o CRC barra quase tudo |
| Botão dispara sozinho ou em dobro | você pegou o par de pinos errado da chave táctil; use os pinos na diagonal |
| Buzzer dá um clique em vez de apitar | ele é passivo, não ativo: troque os `digitalWrite` de `PINO_BUZZER` por `tone(PINO_BUZZER, 620)` e `noTone(PINO_BUZZER)` |
| Todo toque vira traço | você está segurando mais de 2 unidades — meio segundo, com `UNIDADE` em 250. Toques mais secos, ou aumente `UNIDADE` |
| Todo toque vira ponto | o contrário: nenhum toque chega a meio segundo. Diminua `UNIDADE` |
| Os três LEDs piscam sem parar ao ligar | o rádio não iniciou; confira VCC e GND do módulo |
| Upload no Nano falha com `not in sync: resp=0x00`, dez tentativas | **confirmado em 01/09/2026:** selecione Tools → Processor → *ATmega328P (Old Bootloader)*. O clone fala a 57600 bauds e o IDE tenta 115200 |
| Upload falha e você tem as duas placas no USB | a COM escolhida pode ser a do ESP8266, que também aparece como porta. Desconecte o ESP e veja qual porta some |
| Toda letra sai separada por `[espaco]` | é a pausa entre as suas letras passando de 7 unidades. A 250 ms isso é 1,75 s — normal quando se testa letra por letra |
| O morse está lento ou rápido demais para você | `UNIDADE`, no topo do `transmissor-nano.ino`. Número maior é mais lento |

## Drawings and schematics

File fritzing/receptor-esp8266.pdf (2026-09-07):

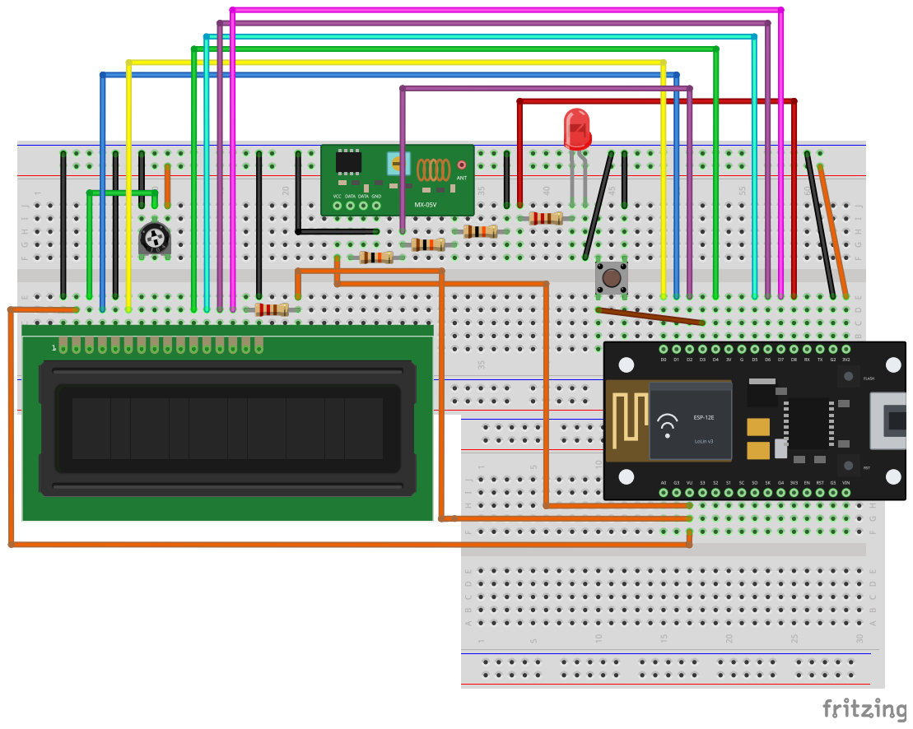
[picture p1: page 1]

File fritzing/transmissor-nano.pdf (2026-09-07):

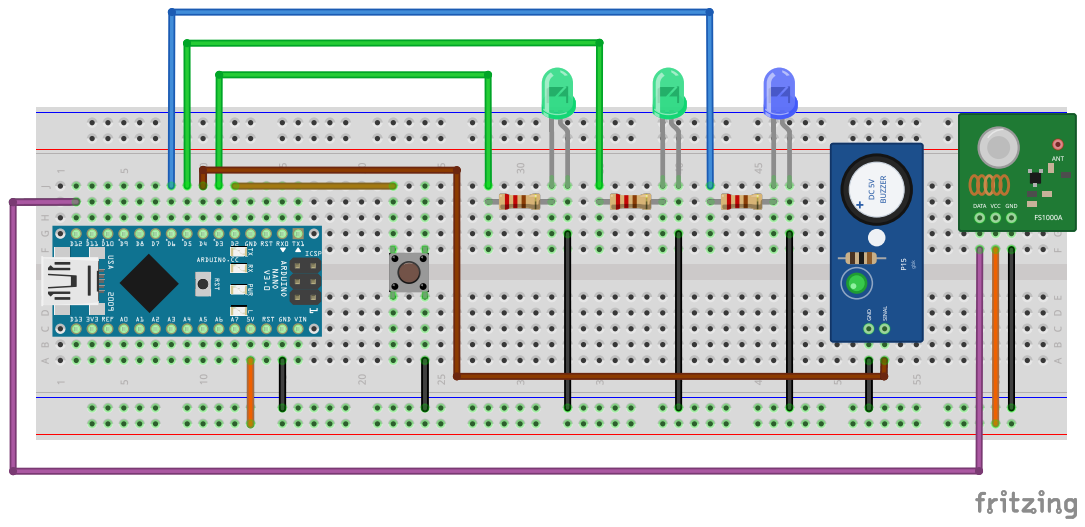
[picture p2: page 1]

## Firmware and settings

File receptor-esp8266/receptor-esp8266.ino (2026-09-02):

/*
  TELEGRAFO SEM FIO - RECEPTOR COM ESP8266

  Faz o mesmo que o receptor-uno.ino — recebe a letra pelo radio 433MHz,
  reconstroi os pontos e tracos e escreve no LCD 16x2 — e ainda publica cada
  letra por MQTT, para a pagina em

      https://henriquemattosesilva.github.io/hw-codigo-morse/ao-vivo/

  mostrar a mensagem ao vivo, de qualquer lugar.

  ---------------------------------------------------------------- ATENCAO
  O ESP8266 e 3,3V e o modulo receptor de 433MHz e 5V. A saida DATA dele
  NAO pode ir direto num pino do ESP: precisa do divisor de 10k + 20k
  descrito no MONTAGEM-ESP8266.md. Ligar direto degrada o pino com o tempo.

  Os pinos GPIO0, GPIO2 e GPIO15 sao lidos no boot e nao aceitam qualquer
  coisa. A distribuicao deles esta explicada em "OS PINOS DE BOOT", logo
  abaixo das constantes — e nao e arbitraria: uma montagem anterior nao
  gravava por causa disso.
  ------------------------------------------------------------------------

  Bibliotecas: RadioHead, PubSubClient (Nick O'Leary) e LiquidCrystal.
  Placa: NodeMCU 1.0 (ESP-12E Module).

  Copie segredos-exemplo.h para segredos.h e ponha os seus dados la. O
  segredos.h esta no .gitignore: a senha do seu WiFi nao vai para o GitHub.
*/

#include <ESP8266WiFi.h>
#include <PubSubClient.h>
#include <RH_ASK.h>
#include <LiquidCrystal.h>
#include "segredos.h"

// ------------------------------------------------------------------ pinos
// Rotulo da placa -> GPIO. O construtor da LiquidCrystal quer o GPIO.
//
// Sao tres os pinos que o ESP le no boot, e cada um deles ficou com a carga
// que empurra para o lado certo. Ver o comentario "OS PINOS DE BOOT" abaixo.
const uint8_t LCD_RS = 5;   // D1
const uint8_t LCD_E  = 16;  // D0 · tambem o LED da placa: vai piscar
const uint8_t LCD_D4 = 2;   // D4 · pino de boot (alto) e LED do modulo
const uint8_t LCD_D5 = 14;  // D5
const uint8_t LCD_D6 = 12;  // D6
const uint8_t LCD_D7 = 13;  // D7
const uint8_t PINO_RADIO  = 4;   // D2 · DATA do receptor, atras do divisor
const uint8_t PINO_LIMPAR = 0;   // D3 · pino de boot (alto); botao ao GND
const uint8_t PINO_LED_RX = 15;  // D8 · pino de boot (baixo); LED ao GND

/*
  OS PINOS DE BOOT, E POR QUE ELES ESTAO ASSIM

  GPIO0, GPIO2 e GPIO15 sao lidos no instante do reset para decidir o modo de
  inicializacao. O que estiver ligado neles tem de deixar o nivel exigido:

      GPIO0  (D3) alto para rodar, baixo para gravar
      GPIO2  (D4) alto
      GPIO15 (D8) baixo

  A primeira montagem punha o LCD nos tres, no raciocinio de que as entradas
  dele ficam em alta impedancia e nao perturbariam nada. Na bancada isso se
  mostrou falso no GPIO15: o LCD e alimentado em 5V pelo VU, e a fuga pelos
  diodos de protecao da entrada RS puxava o pino para cima, vencendo o resistor
  de 12k da placa. O ESP entrava em modo SDIO e a gravacao morria em
  "Timed out waiting for packet header".

  Agora cada pino de boot tem uma carga compativel:

      GPIO0  o botao de limpar, aberto no boot: o pull-up interno o deixa alto.
             E como o proprio botao FLASH da placa e ligado.
      GPIO2  uma linha de dados do LCD: a fuga dos 5V puxa para cima, que e
             justamente o nivel que este pino quer.
      GPIO15 o LED vermelho. Abaixo da tensao direta o LED e quase circuito
             aberto, entao ele nao e um pull-down — o merito e nao brigar com
             o resistor da placa, ao contrario do que o LCD fazia.

  Efeito colateral de por o botao no GPIO0: segurar "limpar" enquanto a placa
  reseta faz o ESP entrar em modo de gravacao. Nao segure no reset.

  O radio continua fora dos tres. A saida dele e ruido aleatorio enquanto nao
  ha transmissao — num pino de boot seria cara ou coroa a cada vez que voce
  ligasse.
*/

LiquidCrystal lcd(LCD_RS, LCD_E, LCD_D4, LCD_D5, LCD_D6, LCD_D7);

// 0xff para transmissao e PTT: este lado so escuta, e nao sobra pino. No
// core do ESP8266 o pinMode de um pino fora de faixa nao faz nada.
RH_ASK radio(2000, PINO_RADIO, 0xff, 0xff);

WiFiClient rede;
PubSubClient mqtt(rede);

// ------------------------------------------------------------- constantes
const uint8_t  MAX_LCD      = 15;   // 15 letras e o cursor cabem na linha 2
const uint16_t MAX_MENSAGEM = 160;  // o ESP tem RAM para guardar bem mais
const uint8_t  COL_MORSE    = 0;
const uint8_t  COL_LETRA    = 7;
const uint8_t  COL_ENLACE   = 13;
const uint8_t  COL_SINAL    = 15;
const uint16_t INDICADOR_MS = 150;
const uint16_t BLOQUEIO_MS  = 200;
const uint16_t ESPERA_MQTT  = 3000;  // entre tentativas de reconexao
const uint16_t ATRASO_TEXTO = 500;   // nao publica a mensagem inteira a cada letra

const char ARVORE_MORSE[] PROGMEM =
  "*ETIANMSURWDKGOHVF*L*PJBXCYZQ**54*3***2*******16*******7***8*90";
const uint8_t ULTIMO_NO = 62;

const uint8_t CHAR_PONTO  = 1;
const uint8_t CHAR_TRACO  = 2;
const uint8_t CHAR_ANTENA = 3;
byte DESENHO_PONTO[8]  = { B00000, B00000, B00000, B01100, B01100, B00000, B00000, B00000 };
byte DESENHO_TRACO[8]  = { B00000, B00000, B00000, B11110, B11110, B00000, B00000, B00000 };
byte DESENHO_ANTENA[8] = { B00001, B00001, B00101, B00101, B10101, B10101, B10101, B00000 };

// ----------------------------------------------------------------- estado
char     mensagem[MAX_MENSAGEM + 1];
uint16_t nMensagem = 0;
uint8_t  ultimaSequencia = 0;

bool          indicadorAceso = false;
unsigned long tIndicador = 0, tLimpar = 0, tMqtt = 0, tTexto = 0;
bool          limparPressionado = false;
bool          textoSujo = false;      // mudou desde a ultima publicacao
bool          enlaceDesenhado = false;
bool          telaInicial = true;     // ainda mostrando "ligando WiFi..."

char topicoLetra[96], topicoTexto[96], topicoStatus[96];

// ------------------------------------------------------------------ setup
void setup() {
  pinMode(PINO_LED_RX, OUTPUT);
  pinMode(PINO_LIMPAR, INPUT_PULLUP);

  lcd.begin(16, 2);
  lcd.createChar(CHAR_PONTO, DESENHO_PONTO);
  lcd.createChar(CHAR_TRACO, DESENHO_TRACO);
  lcd.createChar(CHAR_ANTENA, DESENHO_ANTENA);
  lcd.clear();

  Serial.begin(115200);
  Serial.println();
  Serial.println(F("Telegrafo - receptor ESP8266"));

  snprintf(topicoLetra,  sizeof(topicoLetra),  "%s/letra",    MQTT_TOPICO_BASE);
  snprintf(topicoTexto,  sizeof(topicoTexto),  "%s/mensagem", MQTT_TOPICO_BASE);
  snprintf(topicoStatus, sizeof(topicoStatus), "%s/status",   MQTT_TOPICO_BASE);

  if (!radio.init()) {
    lcd.print(F("ERRO no radio"));
    Serial.println(F("ERRO: radio nao iniciou"));
    while (true) {
      digitalWrite(PINO_LED_RX, HIGH); delay(200);
      digitalWrite(PINO_LED_RX, LOW);  delay(200);
    }
  }

  lcd.setCursor(0, 0); lcd.print(F("MORSE + WiFi"));
  lcd.setCursor(0, 1); lcd.print(F("ligando WiFi..."));

  WiFi.mode(WIFI_STA);
  WiFi.begin(WIFI_SSID, WIFI_SENHA);
  mqtt.setServer(MQTT_SERVIDOR, MQTT_PORTA);

  // A tela de abertura fica ate o WiFi entrar, ou ate a primeira letra chegar.
  // Quem troca para a tela de trabalho e o saiDaTelaInicial(), no loop.
  mensagem[0] = '\0';
  nMensagem = 0;
}

// ------------------------------------------------------------------- loop
void loop() {
  unsigned long agora = millis();

  recebeRadio(agora);
  cuidaDoMqtt(agora);
  if (telaInicial && WiFi.status() == WL_CONNECTED) {
    Serial.println(F("WiFi conectado"));
    saiDaTelaInicial();
  }
  desenhaEnlace();

  if (indicadorAceso && (agora - tIndicador) >= INDICADOR_MS) {
    indicadorAceso = false;
    digitalWrite(PINO_LED_RX, LOW);
    lcd.setCursor(COL_SINAL, 0);
    lcd.write(' ');
  }

  bool limpar = (digitalRead(PINO_LIMPAR) == LOW);
  if (limpar != limparPressionado && (agora - tLimpar) >= BLOQUEIO_MS) {
    tLimpar = agora;
    limparPressionado = limpar;
    if (limpar) limpaMensagem(true);
  }

  // A mensagem inteira sai no maximo duas vezes por segundo; a letra sozinha
  // sai na hora. Publicar o texto todo a cada letra encheria o broker sem
  // deixar a tela mais rapida.
  if (textoSujo && (agora - tTexto) >= ATRASO_TEXTO) publicaMensagem();
}

// ------------------------------------------------------------------ radio
void recebeRadio(unsigned long agora) {
  uint8_t buffer[RH_ASK_MAX_MESSAGE_LEN];
  uint8_t tamanho = sizeof(buffer);
  if (!radio.recv(buffer, &tamanho)) return;
  if (tamanho != 3 || buffer[0] != 'M' || buffer[1] == ultimaSequencia) return;

  ultimaSequencia = buffer[1];
  char c = (char)buffer[2];
  Serial.println(c);

  // Se uma letra chegar antes do WiFi entrar, a tela de trabalho comeca aqui.
  if (telaInicial) saiDaTelaInicial();

  acrescenta(c);
  desenhaLinha1(c);
  desenhaLinha2();

  char morse[8];
  morseDaLetra(c, morse);
  char carga[16];
  // A pagina refaz o morse sozinha a partir da letra, mas mandar os dois
  // deixa o monitor certo mesmo se um dia as tabelas divergirem.
  snprintf(carga, sizeof(carga), "%c %s", c == ' ' ? '_' : c, morse);
  if (mqtt.connected()) mqtt.publish(topicoLetra, carga);
  textoSujo = true;

  digitalWrite(PINO_LED_RX, HIGH);
  lcd.setCursor(COL_SINAL, 0);
  lcd.write('*');
  indicadorAceso = true;
  tIndicador = agora;
}

void acrescenta(char c) {
  if (nMensagem >= MAX_MENSAGEM) {
    memmove(mensagem, mensagem + 1, MAX_MENSAGEM - 1);
    nMensagem = MAX_MENSAGEM - 1;
  }
  mensagem[nMensagem++] = c;
  mensagem[nMensagem] = '\0';
}

/*
  Troca a tela de abertura pela de trabalho. Sem isto, escrever a mensagem por
  cima do "MORSE + WiFi" deixaria pedacos do texto antigo espalhados: a
  desenhaLinha1() so mexe nas colunas 0 a 5 e na 7, e o resto do banner fica.
*/
void saiDaTelaInicial() {
  telaInicial = false;
  lcd.clear();
  enlaceDesenhado = false;  // a tela foi limpa, o indicador tem de ser refeito
  limpaMensagem(false);
}

void limpaMensagem(bool publica) {
  nMensagem = 0;
  mensagem[0] = '\0';
  desenhaLinha1(' ');
  desenhaLinha2();
  if (publica) { textoSujo = true; tTexto = 0; }
}

// ------------------------------------------------------------------- mqtt
void cuidaDoMqtt(unsigned long agora) {
  if (WiFi.status() != WL_CONNECTED) return;
  if (mqtt.connected()) { mqtt.loop(); return; }
  if (agora - tMqtt < ESPERA_MQTT) return;
  tMqtt = agora;

  char id[32];
  snprintf(id, sizeof(id), "morse-%06x", ESP.getChipId());
  // Ultima vontade: se o telegrafo cair, o broker avisa a pagina sozinho.
  if (mqtt.connect(id, topicoStatus, 0, true, "desligado")) {
    Serial.println(F("MQTT conectado"));
    mqtt.publish(topicoStatus, "ligado", true);
    publicaMensagem();
  }
}

void publicaMensagem() {
  if (!mqtt.connected()) return;
  mqtt.publish(topicoTexto, mensagem, true);  // retido: quem abrir depois ve
  textoSujo = false;
  tTexto = millis();
}

// --------------------------------------------------------------- display
void desenhaEnlace() {
  // Canto da linha 1: vazio sem WiFi, 'w' com WiFi mas sem broker, antena
  // quando os dois estao de pe.
  bool wifi = (WiFi.status() == WL_CONNECTED);
  bool tudo = wifi && mqtt.connected();
  static bool ultimoWifi = false, ultimoTudo = false;
  if (enlaceDesenhado && wifi == ultimoWifi && tudo == ultimoTudo) return;
  ultimoWifi = wifi; ultimoTudo = tudo; enlaceDesenhado = true;

  lcd.setCursor(COL_ENLACE, 0);
  if (tudo)       lcd.write(CHAR_ANTENA);
  else if (wifi)  lcd.write('w');
  else            lcd.write(' ');
}

void desenhaLinha1(char c) {
  char morse[8];
  morseDaLetra(c, morse);
  uint8_t n = strlen(morse);

  lcd.setCursor(COL_MORSE, 0);
  for (uint8_t i = 0; i < 6; i++) {
    if (i >= n)                lcd.write(' ');
    else if (morse[i] == '.')  lcd.write(CHAR_PONTO);
    else                       lcd.write(CHAR_TRACO);
  }
  lcd.setCursor(COL_LETRA, 0);
  lcd.write(c == ' ' ? '_' : c);
}

void desenhaLinha2() {
  // O LCD mostra o fim da mensagem; a pagina mostra ela inteira.
  uint16_t inicio = (nMensagem > MAX_LCD) ? nMensagem - MAX_LCD : 0;
  uint16_t visiveis = nMensagem - inicio;
  lcd.setCursor(0, 1);
  for (uint8_t i = 0; i < 16; i++) {
    if (i < visiveis)       lcd.write(mensagem[inicio + i]);
    else if (i == visiveis) lcd.write('_');
    else                    lcd.write(' ');
  }
}

void morseDaLetra(char c, char *saida) {
  saida[0] = '\0';
  int8_t no = -1;
  for (uint8_t i = 1; i <= ULTIMO_NO; i++) {
    if ((char)pgm_read_byte(&ARVORE_MORSE[i]) == c) { no = (int8_t)i; break; }
  }
  if (no < 0) return;

  char invertido[8];
  uint8_t n = 0;
  while (no > 0) {
    invertido[n++] = (((no - 1) % 2) == 0) ? '.' : '-';
    no = (no - 1) / 2;
  }
  for (uint8_t i = 0; i < n; i++) saida[i] = invertido[n - 1 - i];
  saida[n] = '\0';
}

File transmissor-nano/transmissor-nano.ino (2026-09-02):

/*
  TELEGRAFO SEM FIO - TRANSMISSOR (Arduino Nano)

  O botao e um manipulador de morse de verdade: toque curto vira ponto, toque
  longo vira traco, e as pausas separam letras e palavras. A letra fechada e
  decodificada aqui e sai pelo radio 433MHz ja como caractere ASCII.

  Os tres LEDs mostram os limiares de tempo do morse, que normalmente sao
  invisiveis, e acendem ANTES de voce soltar o botao:

      um verde aceso    -> o toque em curso ainda e um ponto
      os dois verdes    -> o toque ja passou de 2 unidades, virou traco
      azul aceso        -> silencio passou de 3 unidades, a letra foi enviada
      azul piscando 2x  -> silencio passou de 7 unidades, espaco enviado

  A unidade de tempo e fixa em UNIDADE, la embaixo. Para mudar o ritmo, troque
  esse numero e regrave. O buzzer apita junto com o toque, como sidetone.

  Biblioteca necessaria: RadioHead (Mike McCauley), no Library Manager.
  Placa: Arduino Nano, processador ATmega328P (Old Bootloader nos clones).
*/

#include <RH_ASK.h>
#include <SPI.h>  // a RadioHead nao usa SPI aqui, mas exige o include para compilar

// ---------------------------------------------------------------- pinos
const uint8_t PINO_BOTAO  = 2;   // chave tactil, outro terminal no GND
const uint8_t PINO_PONTO  = 3;   // LED verde 1 + resistor 220R
const uint8_t PINO_BUZZER = 4;   // buzzer ativo, so S e GND
const uint8_t PINO_TRACO  = 5;   // LED verde 2 + resistor 220R
const uint8_t PINO_ESPACO = 6;   // LED azul    + resistor 220R
// D12 e o DATA do modulo transmissor, padrao da RH_ASK no AVR.

// ------------------------------------------------------------- constantes
// A unidade de tempo do morse, em ms. Tudo o mais e multiplo dela: ponto 1,
// traco 3, pausa entre letras 3, entre palavras 7. Numero maior, morse mais
// lento. 250 e confortavel para aprender; abaixo de 100 ja e bem rapido.
const uint16_t UNIDADE        = 250;
const uint8_t  DEBOUNCE_MS    = 25;   // transicoes mais rapidas que isso sao ruido
const uint8_t  MAX_SIMBOLOS   = 6;    // pontos e tracos por letra
const uint8_t  REPETICOES     = 3;    // copias de cada caractere no ar
const uint16_t PISCA_MS       = 80;   // meio periodo do pisca do LED azul

/*
  Arvore binaria do morse, a mesma tabela usada pelo receptor.
  Comecando na raiz (indice 0), um ponto desce para 2i+1 e um traco para 2i+2.
  O '*' marca posicoes sem letra correspondente.
*/
const char ARVORE_MORSE[] PROGMEM =
  "*ETIANMSURWDKGOHVF*L*PJBXCYZQ**54*3***2*******16*******7***8*90";
const uint8_t ULTIMO_NO = 62;

RH_ASK radio;  // 2000 bps, TX em D12

// ----------------------------------------------------------------- estado
char     simbolos[MAX_SIMBOLOS + 1];  // pontos e tracos da letra em construcao
uint8_t  nSimbolos = 0;

bool     pressionado = false;
unsigned long tTransicao = 0;  // ultima borda aceita, para o debounce
unsigned long tInicio    = 0;  // inicio do toque atual
unsigned long tSoltura   = 0;  // fim do ultimo toque

bool     aguardandoEspaco = false;  // letra fechada, espaco de palavra ainda nao saiu
uint8_t  sequencia = 0;

uint8_t  piscaRestante = 0;
unsigned long tPisca = 0;

uint8_t  pacote[3];
uint8_t  repeticoesPendentes = 0;

// ------------------------------------------------------------------ setup
void setup() {
  pinMode(PINO_BOTAO, INPUT_PULLUP);
  pinMode(PINO_PONTO, OUTPUT);
  pinMode(PINO_TRACO, OUTPUT);
  pinMode(PINO_ESPACO, OUTPUT);
  pinMode(PINO_BUZZER, OUTPUT);

  Serial.begin(9600);
  Serial.println(F("Telegrafo - transmissor"));

  if (!radio.init()) {
    Serial.println(F("ERRO: radio nao iniciou"));
    while (true) {  // pisca os tres LEDs para sempre
      digitalWrite(PINO_PONTO, HIGH); digitalWrite(PINO_TRACO, HIGH);
      digitalWrite(PINO_ESPACO, HIGH); delay(200);
      digitalWrite(PINO_PONTO, LOW); digitalWrite(PINO_TRACO, LOW);
      digitalWrite(PINO_ESPACO, LOW); delay(200);
    }
  }

  testeInicial();
  simbolos[0] = '\0';
  tSoltura = millis();
  Serial.print(F("unidade: ")); Serial.print(UNIDADE); Serial.println(F("ms"));
}

// Acende os LEDs em sequencia e da um bipe. Confere a fiacao sem multimetro.
void testeInicial() {
  const uint8_t leds[3] = { PINO_PONTO, PINO_TRACO, PINO_ESPACO };
  for (uint8_t i = 0; i < 3; i++) {
    digitalWrite(leds[i], HIGH); delay(150); digitalWrite(leds[i], LOW);
  }
  digitalWrite(PINO_BUZZER, HIGH); delay(80); digitalWrite(PINO_BUZZER, LOW);
}

// ------------------------------------------------------------------- loop
void loop() {
  unsigned long agora = millis();
  bool nivel = (digitalRead(PINO_BOTAO) == LOW);  // pull-up: LOW = pressionado

  // Borda de subida ou descida, filtrando repiques do contato.
  if (nivel != pressionado && (agora - tTransicao) >= DEBOUNCE_MS) {
    tTransicao = agora;
    pressionado = nivel;
    if (pressionado) inicioDoToque(agora);
    else             fimDoToque(agora);
  }

  if (pressionado) {
    // O segundo verde acende no instante em que o toque deixa de ser um ponto.
    if (agora - tInicio >= 2UL * UNIDADE) digitalWrite(PINO_TRACO, HIGH);
  } else {
    unsigned long silencio = agora - tSoltura;
    if (nSimbolos > 0 && silencio >= 3UL * UNIDADE) {
      fechaLetra();
    } else if (nSimbolos == 0 && aguardandoEspaco && silencio >= 7UL * UNIDADE) {
      enviaCaractere(' ');
      Serial.println(F("[espaco]"));
      aguardandoEspaco = false;
      piscaRestante = 4;
      tPisca = agora;
      digitalWrite(PINO_ESPACO, LOW);
    }
  }

  atualizaPisca(agora);
  bombeiaRadio();
}

// ------------------------------------------------------------ manipulador
void inicioDoToque(unsigned long agora) {
  tInicio = agora;
  digitalWrite(PINO_PONTO, HIGH);   // todo toque comeca valendo um ponto
  digitalWrite(PINO_TRACO, LOW);
  digitalWrite(PINO_ESPACO, LOW);   // voltou a manipular: cancela o espaco pendente
  digitalWrite(PINO_BUZZER, HIGH);
  piscaRestante = 0;
  aguardandoEspaco = false;
}

void fimDoToque(unsigned long agora) {
  unsigned long duracao = agora - tInicio;
  tSoltura = agora;
  digitalWrite(PINO_PONTO, LOW);
  digitalWrite(PINO_TRACO, LOW);
  digitalWrite(PINO_BUZZER, LOW);
  registraSimbolo(duracao >= 2UL * UNIDADE ? '-' : '.');
}

void registraSimbolo(char s) {
  if (nSimbolos >= MAX_SIMBOLOS) {
    // Um setimo simbolo nao existe no morse. Fecha como desconhecido em vez
    // de escrever fora do buffer.
    Serial.println(F("simbolos demais = ?"));
    enviaCaractere('?');
    nSimbolos = 0;
    simbolos[0] = '\0';
    aguardandoEspaco = true;
    digitalWrite(PINO_ESPACO, HIGH);
    return;
  }
  simbolos[nSimbolos++] = s;
  simbolos[nSimbolos] = '\0';
}

void fechaLetra() {
  char c = decodifica(simbolos);
  Serial.print(simbolos); Serial.print(F(" = ")); Serial.println(c);
  enviaCaractere(c);
  nSimbolos = 0;
  simbolos[0] = '\0';
  aguardandoEspaco = true;
  digitalWrite(PINO_ESPACO, HIGH);
}
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

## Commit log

2026-08-31 Telégrafo sem fio em morse: Nano manipulador, Uno com LCD, rádio 433 MHz
    Manipulador de morse de verdade: o toque curto vira ponto, o longo vira traço
    e as pausas separam letras e palavras. A letra é decodificada no Nano antes de
    ir pelo ar, porque o 433 AM perde pulsos curtos com facilidade — assim uma
    interferência some com a letra inteira em vez de transformá-la em outra.
    Os dois sketches compartilham a mesma árvore binária de 63 bytes: o transmissor
    desce a árvore para achar a letra, o receptor sobe pelos pais para remontar os
    pontos e traços do display. Uma tabela só, sem como divergir.
    Três LEDs marcam os limiares de 2, 3 e 7 unidades, acendendo antes de o
    operador solt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
    [receptor-uno.ino, transmissor-nano.ino]
2026-08-31 Fixa as quebras de linha em LF
    O index.html e os SVGs saem de script Python, que escreve LF. Numa máquina
    sem core.autocrlf=true o arquivo gerado apareceria inteiro como alterado a
    cada regeração, deixando o diff inútil.
2026-08-31 Montagem desenhada peça por peça, para simular no Tinkercad
    O Tinkercad não tem Arduino Nano, não tem módulo de rádio 433 MHz e não
    aceita biblioteca externa, então o projeto não roda lá como está. Mas o
    rádio já era um link serial: o transmissor manda bytes por um pino e o
    receptor lê no dele. Trocando os dois módulos por um fio de D12 a D11 e a
    RadioHead por SoftwareSerial, os pinos continuam os mesmos e toda a lógica
    de morse, o protocolo de 3 bytes e o display passam a ser simulados.
    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
2026-08-31 CLAUDE.md com o estado do projeto e o que ainda não foi testado
    Nada foi montado ainda: tudo o que existe é código que compila e uma tabela
    de morse conferida contra a ITU. O arquivo separa o que foi verificado do
    que foi só raciocinado — polaridade do buzzer, serigrafia dos módulos RF,
    convivência da RH_ASK com a LiquidCrystal no Uno, e os números escolhidos no
    chute educado (três repetições, 25 ms de debounce, faixa de 60 a 250 ms).
    Registra também as decisões que não devem ser desfeitas sem saber o que
    resolvem, com destaque para o bombeiaRadio(): send() bloqueia esperando o
    pacote anterior, então mandar as três cópias em sequência travaria o Nano
    por 200 ms e perderia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
2026-09-02 Receptor com ESP8266 publicando a mensagem na internet, e dois LEDs verdes
    O ESP8266 entra como segundo receptor, ao lado do Uno. Continua escrevendo no
    LCD e passa a publicar por MQTT, com uma página em ao-vivo/ que mostra a
    mensagem em tempo real de qualquer lugar.
    Três coisas mudam ao trocar o Uno pelo ESP, e nenhuma é opcional. A saída do
    módulo de rádio entrega 5 V num pino que não tolera isso, então entra um
    divisor de 10 k + 20 k. GPIO0, GPIO2 e GPIO15 são lidos no boot, e o rádio não
    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
2026-09-02 Buzzer de dois pinos, e o ESP vira subseção da montagem
    O buzzer tem só S e GND: não existe pino de VCC, então quem o alimenta é o
    próprio D4 ao ir para nível alto. Isso tira uma linha errada do guia de
    problemas — "buzzer apita parado e cala ao apertar, inverta HIGH e LOW" era
    impossível de acontecer aqui, porque sem VCC o nível alto é a única forma de
    dar energia a ele. No lugar entrou o sintoma que de fato pode aparecer: se der
    um clique em vez de apitar, ele é passivo e o caso é tone().
    Também vale registrar que são 20 a 30 mA saindo de um pino que recomenda 20,
    e que um C945 com 10 kΩ na base resolve para quem quiser poupar o pino.
    O bloco do ESP8266 deixa de ser se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
    [transmissor-nano.ino]
2026-09-02 Diagrama do divisor mostra o módulo inteiro, não só a linha de dados
    O desenho anterior começava no pino DATA e deixava VCC e GND de fora, então
    não dava para ver onde os quatro pinos do módulo vão parar — que é justamente
    a dúvida que apareceu.
    Agora o módulo aparece com os quatro pinos e cada um com seu destino: VCC no
    VU, GND no G, um DATA descendo pelo divisor e o outro marcado como livre,
    porque os dois do meio são o mesmo ponto por dentro da plaquinha.
    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
2026-09-02 Montagem em abas por placa, com o código de cada uma dobrável
    O código do ESP ficava junto da montagem dele enquanto os outros dois viviam
    numa seção separada. Agora vale a mesma regra para os três: cada sketch mora
    ao lado da fiação da placa a que pertence.
    A montagem virou três abas — Transmissor Nano, Receptor Uno, Receptor ESP8266 —
    e cada uma termina com o seu código dobrado, aberto e fechado no clique. A
    seção "Código das placas" deixou de existir.
    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
2026-09-02 Consolida o CLAUDE.md antes da montagem
    Registra o que mudou nesta rodada e não estava no documento: os dois receptores
    possíveis, o caminho até a internet, a página reorganizada em abas por placa e a
    saída do Tinkercad.
    Três coisas que a próxima sessão não teria como deduzir:
    O tópico MQTT precisa bater em dois lugares — segredos.h e ao-vivo/index.html.
    Divergindo, a página escuta um telégrafo que não é o dele, sem erro nenhum.
    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
2026-09-02 Registra o transmissor funcionando na bancada
    Primeiro teste com hardware real. O Nano grava e o manipulador decodifica
    certo no monitor serial (E e T, unidade em 250ms).
    Sintomas reais que entram na tabela de problemas, no lugar de causas
    supostas:
    - upload falha com "not in sync: resp=0x00" dez vezes -> o clone precisa do
    ATmega328P (Old Bootloader), 57600 bauds em vez de 115200
    - com as duas placas no USB, a COM escolhida pode ser a do ESP8266
    - toda letra sair separada por [espaco] nao e defeito: a 250ms por unidade o
    espaco de palavra e 1,75s
    - "unidade: 250ms" fixo so e impresso no setup(); girar o potenciometro e
    resetar e o jeito de conferir o A0
    Saem da lista de nao testado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
2026-09-02 Tira o potenciometro de velocidade do transmissor
    Na bancada o extremo rapido da faixa (60ms) se mostrou inutil e os 250ms do
    extremo lento eram o unico ponto usado. Um controle cujo curso inteiro e ruim
    menos uma ponta nao paga o componente, o fio e o pino.
    A velocidade continua ajustavel: virou a constante UNIDADE, no topo do sketch.
    O que se perdeu foi ajustar sem regravar.
    - transmissor-nano.ino: sai PINO_POT, UNIDADE_LENTA, UNIDADE_RAPIDA e
    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
2026-09-02 Define o topico MQTT do telegrafo
    O sufixo saiu de "troque-este-sufixo" para um proprio, nos dois lugares que
    precisam bater: o TOPICO_BASE do ao-vivo/index.html (aqui) e o
    MQTT_TOPICO_BASE do segredos.h (fora do versionamento).
    O segredos-exemplo.h fica como esta: quem clonar precisa escolher o seu.
2026-09-02 Registra o ESP8266 conectando na bancada
    Com a placa pelada, sem nenhum fio, o serial mostrou "MQTT conectado" e um
    cliente MQTT externo confirmou .../status = "ligado" retida no broker. WiFi,
    broker e topico conferidos.
    Sintomas reais que entram no guia do ESP8266:
    - "Timed out waiting for packet header": o Nano e a NodeMCU aparecem os dois
    como USB-SERIAL CH340 e a lista de portas nao distingue. E o primeiro a
    conferir, antes de suspeitar do boot
    - "could not open port": a porta sumiu naquele instante, quase sempre cabo
    desencostado
    - o lixo no serial ao resetar e o bootloader de ROM a 74880 bauds, nao defeito
    - radio.init() no ESP8266 nao detecta hardware, entao da para testar WiF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
2026-09-02 Tira o LCD dos pinos de boot do ESP8266
    Com o LCD ligado, o ESP nunca aceitava gravacao: "Timed out waiting for
    packet header", sempre. Tres testes isolaram a causa. Tirar o D3 nao
    resolvia; tirar o D8 resolvia.
    Era o RS do LCD no GPIO15. O display e alimentado em 5V pelo VU e a fuga
    pelos diodos de protecao da entrada puxava o pino para cima, vencendo o
    resistor de 12k da placa. O ESP entrava em modo SDIO em vez de aceitar
    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
2026-09-02 Conserta o resto do banner na tela do ESP8266
    O setup escrevia "MORSE + WiFi" e logo em seguida chamava limpaMensagem(),
    que so apaga as colunas 0 a 5 e escreve o cursor na 7. Sobravam o "+" da
    coluna 6 e o "WiFi" das 8 a 11, e a tela de repouso aparecia como "+_WiFi".
    Agora existe saiDaTelaInicial(): da um lcd.clear(), invalida o
    enlaceDesenhado e desenha a tela de trabalho. Ela e chamada quando o WiFi
    entra, ou quando a primeira letra chega, o que vier antes.
    De brinde, a tela "ligando WiFi..." passou a ficar visivel de verdade -- ela
    era sobrescrita microssegundos depois de ser escrita -- e o serial agora
    imprime "WiFi conectado", que separa problema de rede de problema de broker.
    Comp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
    [receptor-esp8266.ino]
2026-09-02 Acrescenta um teste de enlace de radio para o Uno
    Nenhuma letra chegou ao ESP8266 ate agora, e o serial do transmissor nao
    prova transmissao: ele decodifica antes do radio entrar. Faltava uma forma de
    saber se o 433MHz esta chegando sem depender de WiFi, LCD, divisor e 3,3V ao
    mesmo tempo.
    O sketch escuta com o Uno, que e 5V nativo como os modulos, e imprime cada
    pacote em hexa mais um balanco com rxGood e rxBad da RadioHead. Essas duas
    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
2026-09-02 Conta transicoes no pino do radio, e corrige a leitura do teste
    A tabela de interpretacao que eu tinha escrito estava errada num ramo. O
    _rxBad da RH_ASK so incrementa depois que a biblioteca reconheceu o simbolo
    de inicio do quadro: ou o CRC falha no fim (validateRxBuf), ou o byte de
    tamanho vem absurdo. Com a amostragem muito desalinhada o inicio nunca e
    reconhecido, e "boas: 0 mas: 0" fica identico ao caso de fio morto.
    Ou seja, as duas contagens zeradas nao distinguiam problema eletrico de
    problema de tempo -- que e justamente a pergunta do teste.
    Agora o balanco traz "transicoes/20ms": bordas lidas direto do pino, fora da
    RH_ASK. O receptor AM abre o ganho quando nao ha transmissao e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
    [teste-radio-esp.ino]
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2026-09-05 Fecha o enlace: era alimentacao do modulo, nao disputa com o WiFi
    O radio nunca chegou ao ESP8266 por dois erros eletricos empilhados. Primeiro
    o fio do VU estava num dos pinos DATA do modulo, e nao no de alimentacao: o
    receptor desta bancada tem o GND no primeiro pino e o VCC no quarto, o inverso
    do que os diagramas desenhavam. Corrigido isso, a linha + da protoboard ainda
    vinha do 3V e nao do VU, e o receptor de 433 MHz e superregenerativo: em 3,3 V
    ele fica mudo sem nenhum aviso. Passar para o VU fez funcionar na hora.
    Com isso a hipotese do WiFi comendo as interrupcoes cai, e o teste-radio-esp
    nunca precisou ser rodado. Ele fica no repositorio para o caso de aparecer
    perda de letra, mas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
2026-09-06 Acrescenta o sketch do Fritzing, e diz de que lado se le a serigrafia
    fritzing/ traz o desenho de protoboard das duas montagens numa prancha so:
    em cima o transmissor com o Nano, embaixo o receptor com o ESP8266, o LCD e o
    divisor. O .fzz e a fonte; o PNG e o PDF sao exportacoes feitas a mao pelo
    Fritzing, sem script, entao mexer no sketch obriga a reexportar os dois.
    O sketch depende das duas pecas de radio que moram no hw-laboratorio, com os
    ids rf433-tx e rf433-rx. Sem instalar de la, ele abre com as pecas faltando.
    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
    [sketch-codigo-morse.fzz]
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2026-09-06 Registra os quatro erros do sketch do Fritzing
    Conferido extraindo a netlist do .fzz e comparando com os sketches e com a
    fiacao documentada. O hardware da bancada esta certo; quem discorda e o
    desenho:
    1. o VCC do transmissor sai do VIN do Nano, que e entrada do regulador, e o
    pino 5V nao vai a lugar nenhum. Montado assim o modulo nao liga.
    2. D4 e D5 trocados: o desenho poe o LED verde 2 no D4 e o buzzer no D5, e o
    firmware faz o contrario.
    3. o pino 15 do LCD vai direto nos 5 V, sem o resistor que o MONTAGEM.md diz
    nao ser opcional.
    4. a peca do ESP e a NodeMCU Amica e nao a LoLin v3: o pino que recebe 5 V e
    o VU na LoLin, certo, mas RSV na Amica, reservado.
    Fica registrado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
2026-09-06 Registra o trilho que nao era o terra, e o quadrado que nao e contraste
    Depois de remontar a protoboard o LCD passou a mostrar so quadrados pretos, com
    o contraste sem efeito nenhum. Era o pino 5 (RW) num ponto do trilho negativo
    que nao era o terra do ESP; ligado direto no G da placa, o display voltou.
    Duas correcoes nos documentos, e a primeira e a que mais importa:
    A tabela de problemas dizia "fileira de blocos pretos -> contraste no extremo
    errado". Isso e so metade: quadrado preto uniforme e o estado de um HD44780 que
    tem energia e contraste mas nunca recebeu comando de inicializacao. Se o
    contraste nao muda nada, o problema e de controle -- RW, E, ou o terra do
    display nao ser o mesm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
2026-09-07 Separa o Fritzing em um sketch por placa, os dois conferidos
    A prancha unica virou transmissor-nano.fzz e receptor-esp8266.fzz. Quem monta
    trabalha em uma placa de cada vez, e a prancha unica obrigava a achar a metade
    certa antes de comecar.
    Os quatro erros da conferencia de ontem foram corrigidos nos arquivos novos: o
    VCC do transmissor saiu do VIN e foi para o 5V, D4 e D5 voltaram para a ordem
    do firmware, o pino 15 do LCD ganhou os 220 ohms e a peca do ESP passou a ser a
    LoLin v3, com pino VU de verdade. Os dois sketches foram conferidos por netlist
    e passaram.
    A tabela dos erros fica no documento de proposito. Ela nao e historico: e a
    lista do que esse desenho especifico erra, e serve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
    [receptor-esp8266.fzz, sketch-codigo-morse.fzz, transmissor-nano.fzz]
